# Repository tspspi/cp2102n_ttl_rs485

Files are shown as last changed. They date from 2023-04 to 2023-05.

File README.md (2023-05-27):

# Simple CP2102N USB to TTL and half duplex RS485 board

There is an [accompanying blog article](https://www.tspi.at/2023/05/27/cp2102basics.html) 
that explains the reasoning behind the design of this interface board.

This repository contains a simple open breakout board for the CP2102N. It uses
a simple bus powered design. All unused pins of the CP2102N are exposed via a
16 pin pin-header so one can easily access them to experiment with the more advanced
features of the chip itself. In addition the board contains two LEDs on the GPIO.0
and GPIO.1 pins for TX and RX indication. For RS485 mode it also houses a single
MAX485 and utilizes the CP2102Ns toggle function for transmit and receive switching
on the MAX485. The bus can be optionally terminated with a 120 Ohm resistor by
setting a jumper. Note that the RS485 bus is _not_ galvanically isolated by a
transformer!

One can switch between TTL and RS485 operation by setting JP1 and JP2 accordingly.

## Files

The provided files are:

* The [KiCad](https://www.kicad.org/) sources in ```kicad/cp2102rs485```
* The Gerber production files in the ```gerber``` directory

## License

See [LICENSE.md](./LICENSE.md)

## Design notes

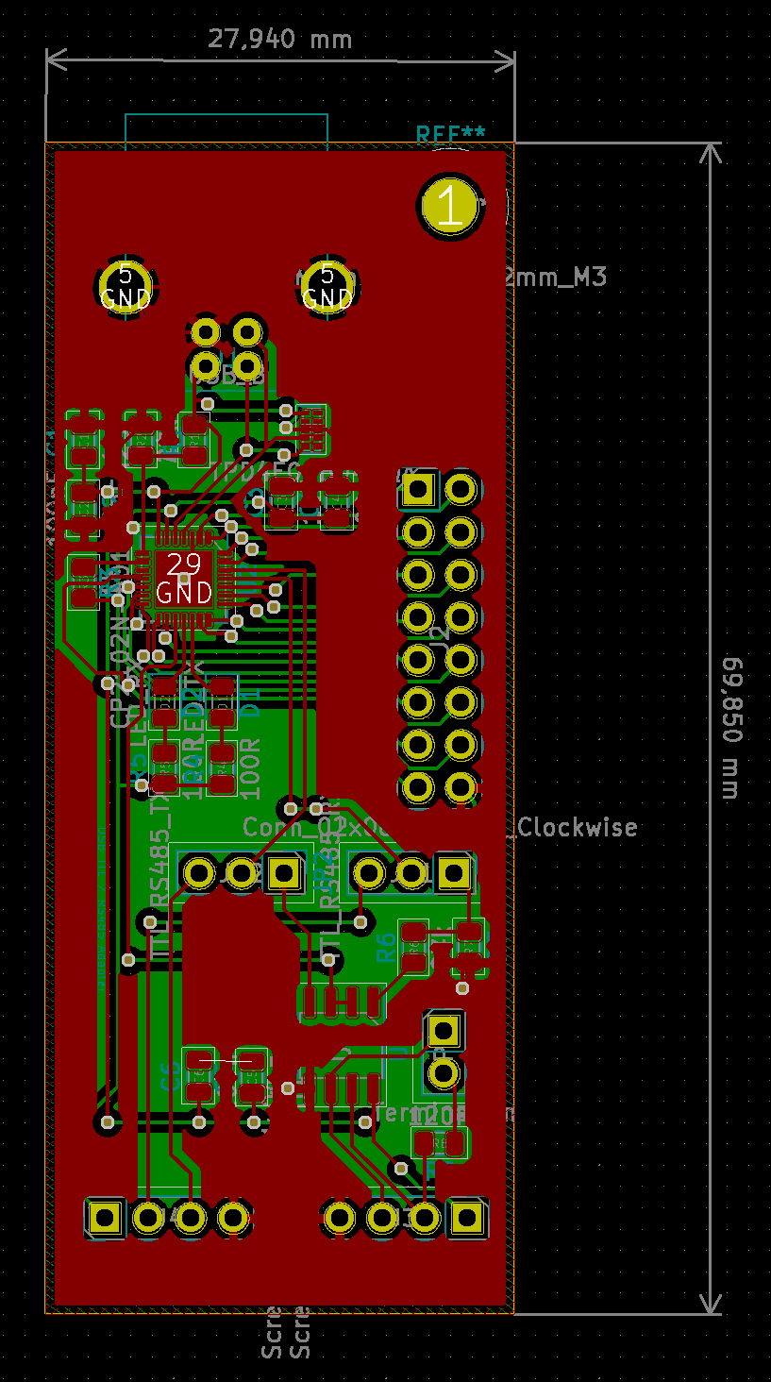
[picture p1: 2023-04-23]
doc/pcbcad.png

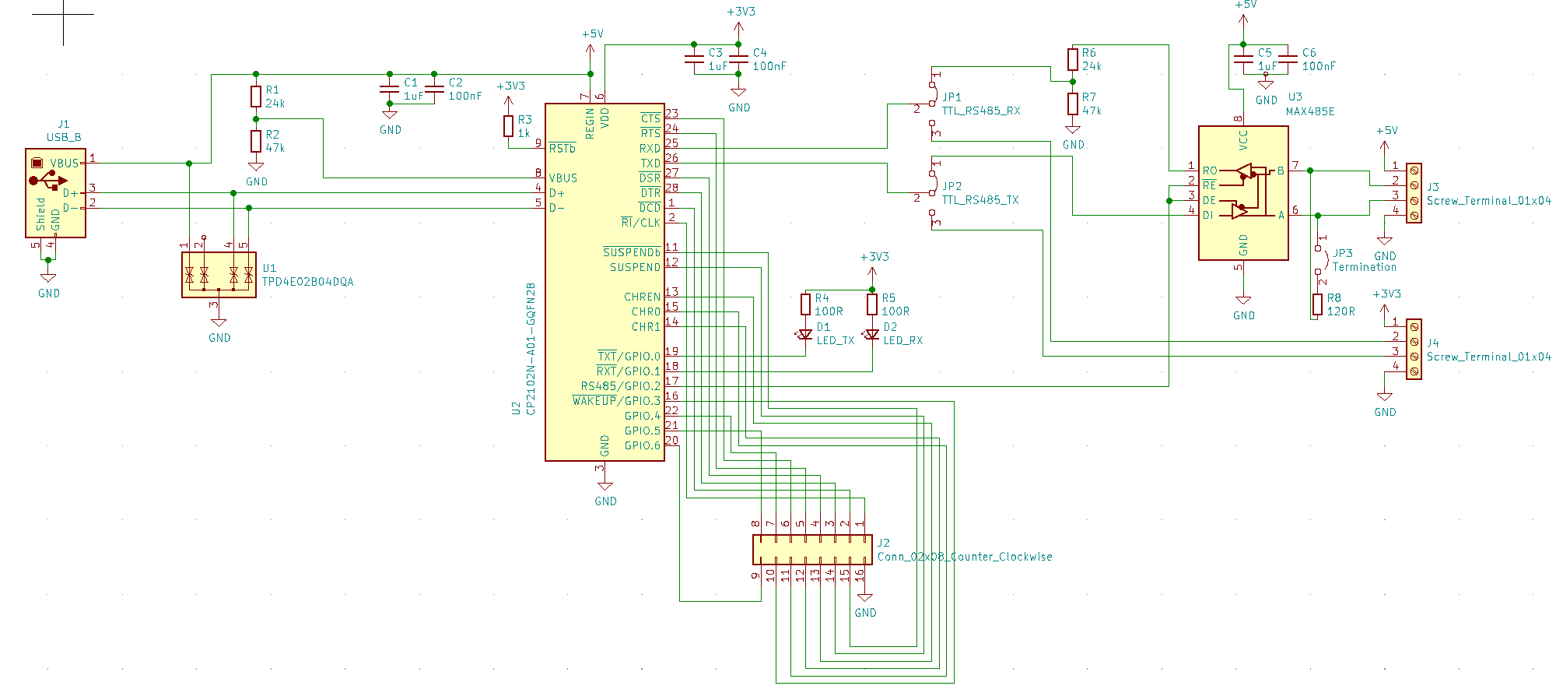
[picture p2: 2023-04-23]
doc/schema.png

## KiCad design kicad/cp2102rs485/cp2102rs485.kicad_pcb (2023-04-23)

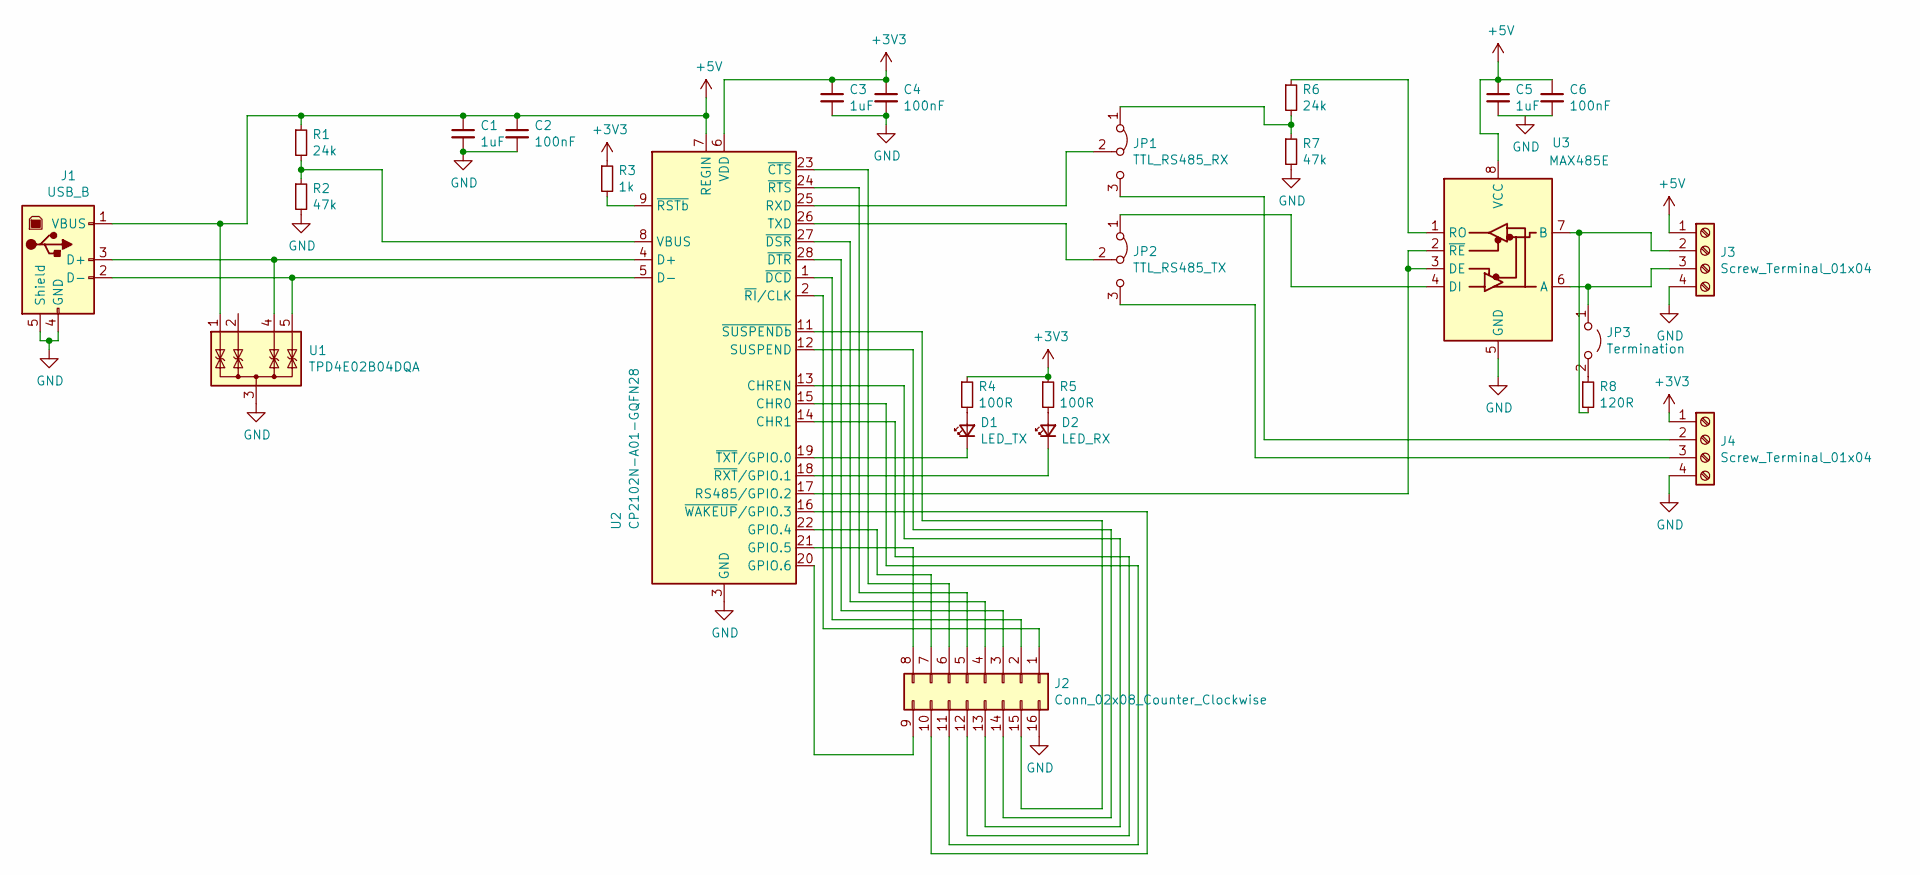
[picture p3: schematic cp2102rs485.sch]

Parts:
C1, C3, C5: 1uF; C_0805_2012Metric
C2, C4, C6: 100nF; C_0805_2012Metric
D1: LED_TX; LED_0805_2012Metric
D2: LED_RX; LED_0805_2012Metric
J1: USB_B; Wurth61400416121; MouserNR 710-61400416121
J2: Conn_02x08_Counter_Clockwise; PinHeader_2x08_P2.54mm_Vertical
J3, J4: Screw_Terminal_01x04; PinHeader_1x04_P2.54mm_Vertical
JP1: TTL_RS485_RX; PinHeader_1x03_P2.54mm_Vertical
JP2: TTL_RS485_TX; PinHeader_1x03_P2.54mm_Vertical
JP3: Termination; PinHeader_1x02_P2.54mm_Vertical
R1, R6: 24k; R_0805_2012Metric
R2, R7: 47k; R_0805_2012Metric
R3: 1k; R_0805_2012Metric
R4, R5: 100R; R_0805_2012Metric
R8: 120R; R_0805_2012Metric
U1: TPD4E02B04DQA; USON-10_2.5x1.0mm_P0.5mm
U2: CP2102N-A01-GQFN28; QFN-28-1EP_5x5mm_P0.5mm_EP3.35x3.35mm
U3: MAX485E; SO-8_3.9x4.9mm_P1.27mm; MouserNR 700-MAX485ESAT

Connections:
+3V3: C3.1, C4.1, J4.1, R3.1, R4.1, R5.1, U2.6 (VDD)
+5V: C1.1, C2.1, C5.1, C6.1, J1.1 (VBUS), J3.1, R1.1, U1.1 (IO1), U2.7 (REGIN), U3.8 (VCC)
unnamed: D1.1 (K), U2.19 (~TXT~/GPIO.0)
unnamed: D1.2 (A), R4.2
unnamed: D2.1 (K), U2.18 (~RXT~/GPIO.1)
unnamed: D2.2 (A), R5.2
unnamed: J1.2 (D-), U1.5 (IO4), U2.5 (D-)
unnamed: J1.3 (D+), U1.4 (IO3), U2.4 (D+)
unnamed: J2.1, U2.2 (~RI~/CLK)
unnamed: J2.2, U2.1 (~DCD)
unnamed: J2.3, U2.28 (~DTR)
unnamed: J2.4, U2.27 (~DSR)
unnamed: J2.5, U2.24 (~RTS)
unnamed: J2.6, U2.23 (~CTS)
unnamed: J2.7, U2.22 (GPIO.4)
unnamed: J2.8, U2.21 (GPIO.5)
unnamed: J2.9, U2.20 (GPIO.6)
unnamed: J2.10, U2.16 (~WAKEUP~/GPIO.3)
unnamed: J2.11, U2.15 (CHR0)
unnamed: J2.12, U2.14 (CHR1)
unnamed: J2.13, U2.13 (CHREN)
unnamed: J2.14, U2.12 (SUSPEND)
unnamed: J2.15, U2.11 (~SUSPENDb)
unnamed: J3.2, R8.2, U3.7 (B)
unnamed: J3.3, JP3.1 (A), U3.6 (A)
unnamed: J4.2, JP1.3 (B)
unnamed: J4.3, JP2.3 (B)
unnamed: JP1.1 (A), R6.2, R7.1
unnamed: JP1.2 (C), U2.25 (RXD)
unnamed: JP2.1 (A), U3.4 (DI)
unnamed: JP2.2 (C), U2.26 (TXD)
unnamed: JP3.2 (B), R8.1
unnamed: R1.2, R2.1, U2.8 (VBUS)
unnamed: R3.2, U2.9 (~RSTb)
unnamed: R6.1, U3.1 (RO)
unnamed: U2.17 (RS485/GPIO.2), U3.2 (~RE), U3.3 (DE)

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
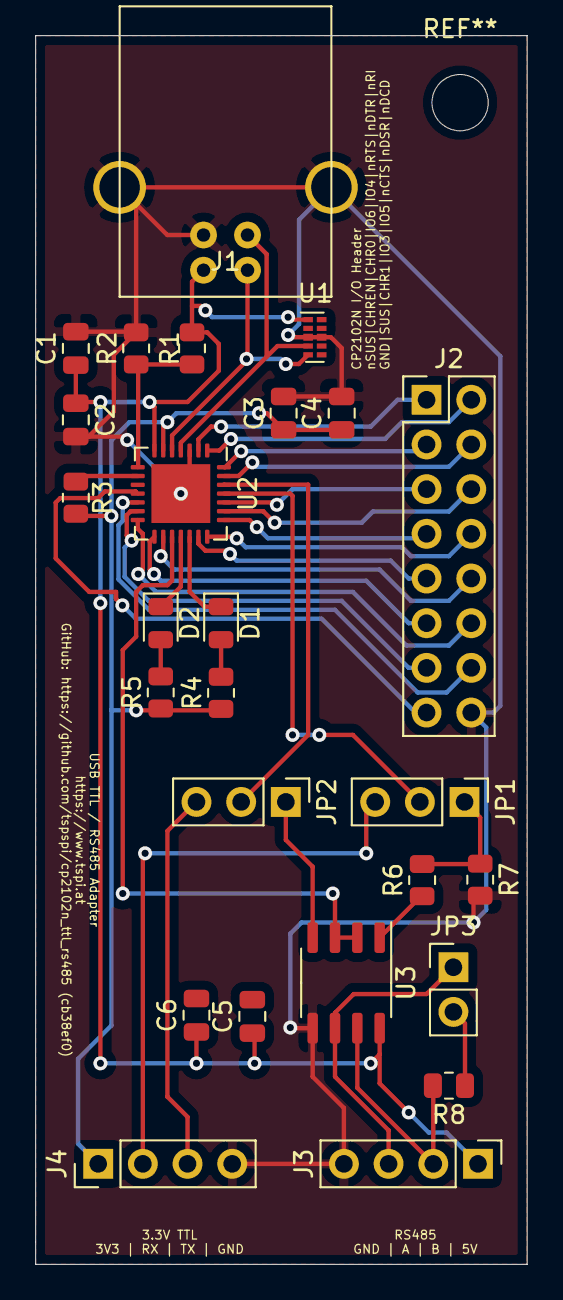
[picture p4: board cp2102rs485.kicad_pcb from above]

Board: 2 copper layers, 27.9 x 69.9 mm, 26 parts (0 on the bottom side), 38 nets.

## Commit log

2023-04-23 Update labeling to reflect commit number
    [cp2102rs485.kicad_pcb]
2023-04-23 Adding Gerber files
    [cp2102rs485-B_Cu.gbl, cp2102rs485-B_Mask.gbs, cp2102rs485-B_Paste.gbp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]
